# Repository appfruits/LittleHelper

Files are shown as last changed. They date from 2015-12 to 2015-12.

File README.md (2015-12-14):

# LittleHelper
This is the Arduino compatible firmware running Little Helper, a little device that is useful in electronic labs. The firmware also shows how to build a more complex LCD based application, featuring a few standard controls.

This software should compile and run on a Teensy 3.1 although you will need a few hardware components to make use of it. Have a look at http://www.appfruits.com/littlehelper. We provide everything from PCB schematics and layout, even enclosings to build your own Little Helper or getting inspired building your own little, useful device.

Copyright 2014-2015 by Phillip Schuster
http://www.appfruits.com

## Hardware
We also added the Eagle PCBs Design, layout and schematics. We also added the Copper file. Copper is a Mac applications that makes it easy to generate 3D models of your Eagle based PCBs and also helps in building a BOM and keeping it up to date. Have a look at http://www.copper-app.com.

## Structure
This software is C++ and shows how to build a nice, stack based application runloop and User Interface that is easily expandable by providing standard controls and protocols and uses the good old MVC structure. 

Running such code on a small 8-bit AVR is overkill, but with all those new ARM MCUs offering a lot of performance, and more importantly offering more RAM allows such code to be written and run even on small devices. This makes it easier to write structured software that you can read in a couple of months from now.

## License
We provide this in a MIT-License. You may use, copy, modify, merge, publish, distribute, sublicense, and/or sell copies of the Software but you must include this copyright notice and this permission in all copies or substantial portions of the Software.

We invest time and resources making this open source. Please support us by spreading your word and purchasing our products.

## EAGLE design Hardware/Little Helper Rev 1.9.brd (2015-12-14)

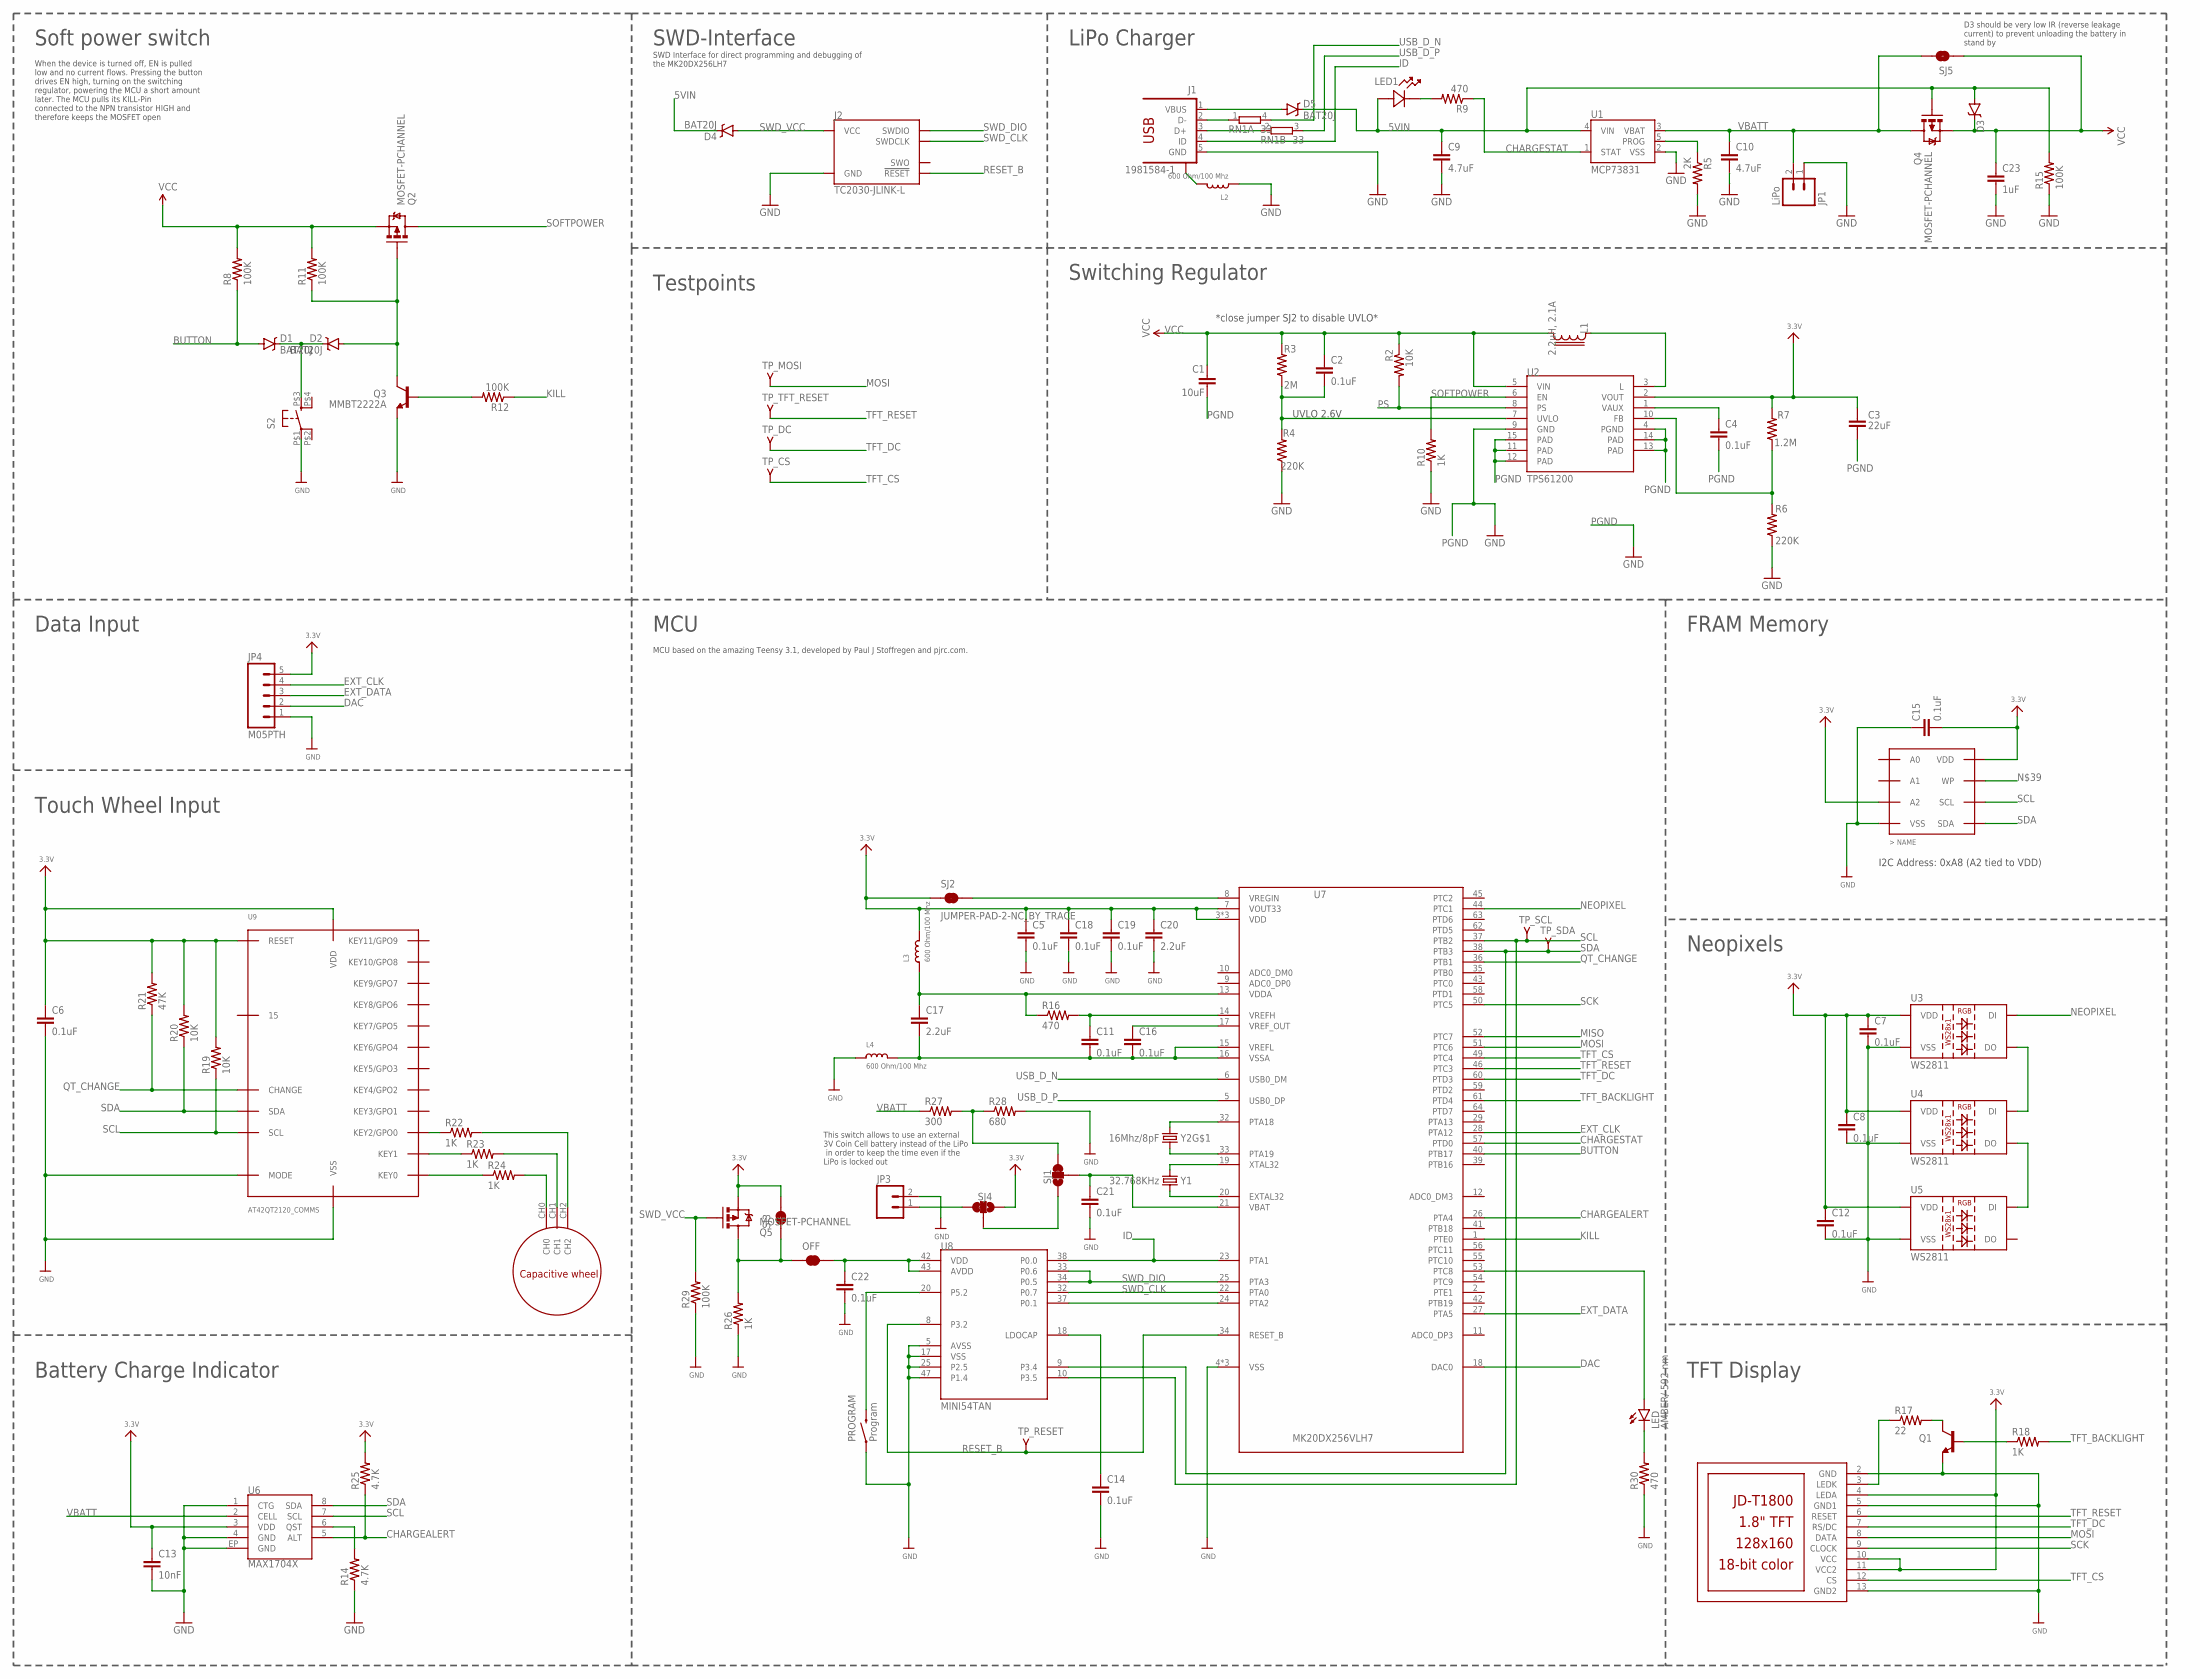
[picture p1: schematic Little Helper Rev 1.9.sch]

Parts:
C1: 10uF; 0603-CAP
C2, C4, C5, C6, C7, C8, C11, C12, C14, C15, C16, C18, C19, C21, C22: 0.1uF; 0603-CAP
C3: 22uF; 0603-CAP
C9, C10: 4.7uF; 0603-CAP
C13: 10nF; 0603-CAP; MPN C0603C103K5RACTU
C17, C20: 2.2uF; 0603-CAP
C23: 1uF; 0603-CAP
D1, D2, D4, D5: BAT20J; SOD-323
D3: DIODE-SCHOTTKY-LOW_LEAKAGE; SOD-323
J1: 1981584-1; MPN ZX62-AB-5PA(11)
J2: TC2030-JLINK-L; TC2030-IDC
JP1: LiPo; JST-2-SMD
JP3: M02PTH; 1X02
JP4: M05PTH; 1X05
L1: 2.2uH, 2.1A; LPS3015
L2, L3, L4: 600 Ohm/100 Mhz; 0805
LCD1: JD-T1800
LED: AMBER/ 592 nm; LED-0603
LED1: 597-2311-407F; LED_597-2311-407F
OFF: JUMPER-PAD-2-NC_BY_TRACE; PAD-JUMPER-2-NC_BY_TRACE_YES_SILK
PROGRAM: Program; TACTILE-SWITCH-1101NE; MPN RS-282G05A3-SM RT
Q1: TRANSISTOR_NPNSOT23-3; SOT23-3
Q2, Q4, Q5: MOSFET-PCHANNEL; SOT23-3; MPN BSS84LT1G
Q3: MMBT2222A; SOT23-3
R2, R19, R20: 10K; 0603-RES
R3: 2M; 0603-RES
R4, R6: 220K; 0603-RES
R5: 2K; 0603-RES
R7: 1.2M; 0603-RES
R8, R11, R12, R15, R29: 100K; 0603-RES
R9, R16, R30: 470; 0603-RES
R10, R18, R22, R23, R24, R26: 1K; 0603-RES
R14, R25: 4.7K; 0603-RES
R17: 22; 0603-RES
R21: 47K; 0603-RES
R27: 300; 0603-RES
R28: 680; 0603-RES
RN1: 33; EXB34V; MPN EXB-34V330JV
S2: TAC_SWITCHPTS645_SERIES; PTS645_BUTTON_SERIES; MPN PTS645SH50SMTR 92 LFS
SJ1, SJ4: JUMPER-PAD-3-2OF3_NC_BY_TRACE; PAD-JUMPER-3-2OF3_NC_BY_TRACE_YES_SILK_FULL_BOX
SJ2: JUMPER-PAD-2-NC_BY_TRACE; PAD-JUMPER-2-NC_BY_TRACE_YES_SILK
SJ3, SJ5: JUMPER-PAD-2-NOYES_SILK; PAD-JUMPER-2-NO_YES_SILK
TP_CS: TPV-PAD-016; PAD-016
TP_DC: TPV-PAD-016; PAD-016
TP_MOSI: MOSI; PAD-016
TP_RESET: TPV-PAD-016; PAD-016
TP_SCL: TPV-PAD-016; PAD-016
TP_SDA: TPV-PAD-016; PAD-016
TP_TFT_RESET: MOSI; PAD-016
U1: MCP73831; SOT23-5; MPN MCP73831T-2ACI/OT
U2: TPS61200; QFN-10_PAD
U3, U4, U5: WS2811; LED-TRICOLOR-5050-IC
U6: MAX1704X; TDFN-8
U7: MK20DX256VLH7; MPN MK20DX256VLH7
U8: MINI54TAN
U9: AT42QT2120_COMMS; QT2120
U12: FM24CL64BSOIC8_150MIL; SO08
U$1: QTWHEEL_MODULE; QTWHEELMODULE
Y1: 32.768KHz; CRYSTAL-TXC-7A; MPN FC-255 32.7680K-A3
Y2: 16Mhz/8pF; CRYSTAL-SMD-5X3; MPN ECS-160-8-30B-CKM

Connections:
3.3V: C3.1, C5.1, C6.1, C7.1, C8.1, C12.1, C13.1, C15.2, C18.1, C19.1, C20.1, JP4.5, L3.2, LCD1.4 (LEDA), LCD1.10 (VCC), LCD1.11 (VCC2), Q5.2 (S), R7.2, R19.2, R20.2, R21.2, R25.2, SJ2.1, SJ3.2, SJ4.1, U2.2 (VOUT), U3.3 (VDD), U3.5 (VDD), U4.3 (VDD), U4.5 (VDD), U5.3 (VDD), U5.5 (VDD), U6.3 (VDD), U7.3 (VDD), U7.7 (VOUT33), U7.30 (VDD), U7.48 (VDD), U9.11 (VDD), U9.14 (RESET), U12.3 (A2), U12.8 (VDD)
5VIN: C9.1, D3.A, D4.C, D5.C, LED1.2, Q4.1 (G), R15.2, U1.4 (VIN)
BUTTON: D1.A, R8.1, U7.40 (PTB17)
CHARGEALERT: R25.1, U6.5 (ALT), U7.26 (PTA4)
CHARGESTAT: R9.1, U1.1 (STAT), U7.57 (PTD0)
DAC: JP4.2, U7.18 (DAC0)
EXT_CLK: JP4.4, U7.28 (PTA12)
EXT_DATA: JP4.3, U7.27 (PTA5)
FB: R6.2, R7.1, U2.10 (FB)
GND: C5.2, C6.2, C7.2, C8.2, C9.2, C10.2, C12.2, C13.2, C14.2, C15.1, C18.2, C19.2, C20.2, C21.2, C22.2, C23.2, J1.5 (GND), J2.5 (GND), JP1.1 (2), JP3.2, JP4.1, L2.1, L4.1, LCD1.2 (GND), LCD1.5 (GND1), LCD1.13 (GND2), PROGRAM.P$1 (1), Q1.2 (E), Q3.2 (E), R4.1, R5.2, R6.1, R10.1, R14.1, R15.1, R26.1, R28.2, R29.1, R30.1, S2.P$1 (1), U1.2 (VSS), U3.6 (VSS), U4.6 (VSS), U5.6 (VSS), U6.1 (CTG), U6.4 (GND), U6.EP (GND), U7.4 (VSS), U7.31 (VSS), U7.47 (VSS), U8.5 (AVSS), U8.17 (VSS), U8.25 (P2.5), U8.47 (P1.4), U9.10 (VSS), U9.12 (MODE), U12.4 (VSS)
ID: J1.4 (ID), U7.23 (PTA1), U8.38 (P0.0)
KILL: R12.1, U7.1 (PTE0)
MISO: U7.52 (PTC7)
MOSI: LCD1.8 (DATA), TP_MOSI.1, U7.51 (PTC6)
unnamed: OFF.1, Q5.3 (D), R26.2, SJ3.1
unnamed: L1.1, U2.3 (L)
unnamed: D2.A, Q2.1 (G), Q3.3 (C), R11.1
unnamed: Q3.1 (B), R12.2
unnamed: D1.C, D2.C, S2.P$3 (3)
unnamed: LED1.1, R9.2
unnamed: C21.1, SJ1.2, U7.21 (VBAT)
unnamed: C22.1, OFF.2, U8.42 (VDD), U8.43 (AVDD)
unnamed: R5.1, U1.5 (PROG)
unnamed: LED.A, U7.53 (PTC8)
unnamed: D5.A, J1.1 (VBUS)
unnamed: JP3.1, SJ4.3
unnamed: U7.24 (PTA2), U8.37 (P0.1)
unnamed: R22.1, U9.7 (KEY2/GPO0)
unnamed: R23.1, U9.8 (KEY1)
unnamed: LED.C, R30.2
unnamed: PROGRAM.P$2 (2), U8.20 (P5.2)
unnamed: SJ1.1, SJ4.2
unnamed: C14.1, U8.18 (LDOCAP)
unnamed: U7.32 (PTA18), Y2.3 (2)
unnamed: U7.33 (PTA19), Y2.1
unnamed: U7.19 (XTAL32), Y1.P$2 (2)
unnamed: U7.20 (EXTAL32), Y1.P$1 (1)
unnamed: R27.2, R28.1, SJ1.3
unnamed: LCD1.3 (LEDK), R17.1
unnamed: R24.1, U9.9 (KEY0)
unnamed: U3.1 (DO), U4.2 (DI)
unnamed: Q1.3 (C), R17.2
unnamed: Q1.1 (B), R18.1
unnamed: R22.2, U$1.CH2
unnamed: R23.2, U$1.CH1
unnamed: R24.2, U$1.CH0
unnamed: U4.1 (DO), U5.2 (DI)
unnamed: R14.2, U6.6 (QST)
NEOPIXEL: U3.2 (DI), U7.44 (PTC1)
PGND: C1.2, C3.2, C4.2, U2.4 (PGND), U2.9 (GND), U2.11 (PAD), U2.12 (PAD), U2.13 (PAD), U2.14 (PAD), U2.15 (PAD)
PS: R2.2, U2.8 (PS)
QT_CHANGE: R21.1, U7.36 (PTB1), U9.17 (CHANGE)
RESET_B: J2.3 (!RESET), TP_RESET.1, U7.34 (RESET_B), U8.8 (P3.2)
SCK: LCD1.9 (CLOCK), U7.50 (PTC5)
SCL: R19.1, TP_SCL.1, U6.7 (SCL), U7.37 (PTB2), U8.10 (P3.5), U9.16 (SCL), U12.6 (SCL)
SDA: R20.1, TP_SDA.1, U6.8 (SDA), U7.38 (PTB3), U8.9 (P3.4), U9.13 (SDA), U12.5 (SDA)
SOFTPOWER: Q2.3 (D), R10.2, U2.6 (EN)
SWD_CLK: J2.4 (SWDCLK), U7.22 (PTA0), U8.32 (P0.7)
SWD_DIO: J2.2 (SWDIO), U7.25 (PTA3), U8.33 (P0.6), U8.34 (P0.5)
SWD_VCC: D4.A, J2.1 (VCC), Q5.1 (G), R29.2
TFT_BACKLIGHT: R18.2, U7.61 (PTD4)
TFT_CS: LCD1.12 (CS), TP_CS.1, U7.49 (PTC4)
TFT_DC: LCD1.7 (RS/DC), TP_DC.1, U7.60 (PTD3)
TFT_RESET: LCD1.6 (RESET), TP_TFT_RESET.1, U7.46 (PTC3)
USB_CON_N: J1.2 (D-), RN1.1
USB_CON_P: J1.3 (D+), RN1.2 (1)
USB_D_N: RN1.4 (2), U7.6 (USB0_DM)
USB_D_P: RN1.3 (2), U7.5 (USB0_DP)
USB_SHIELD: J1.S1, L2.2
UVLO: C2.2, R3.1, R4.2, U2.7 (UVLO)
VAUX: C4.1, U2.1 (VAUX)
VBATT: C10.1, JP1.2 (1), Q4.3 (D), R27.1, SJ5.2, U1.3 (VBAT), U6.2 (CELL)
VCC: C1.1, C2.1, C23.1, D3.C, L1.2, Q2.2 (S), Q4.2 (S), R2.1, R3.2, R8.2, R11.2, SJ5.1, U2.5 (VIN)
VDDA: C17.1, L3.1, R16.1, U7.13 (VDDA)
VREFH: C11.1, R16.2, U7.14 (VREFH)
VREFL: C11.2, C16.2, C17.2, L4.2, U7.15 (VREFL), U7.16 (VSSA)
VREF_OUT: C16.1, U7.17 (VREF_OUT)
VREGIN: SJ2.2, U7.8 (VREGIN)

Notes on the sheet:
UVLO 2.6V
*close jumper SJ2 to disable UVLO*
LiPo Charger
Switching Regulator
Data Input
This switch allows to use an external 3V Coin Cell battery instead of the LiPo in order to keep the time even if the LiPo is locked out
When the device is turned off, EN is pulled low and no current flows. Pressing the button drives EN high, turning on the switching regulator, powering the MCU a short amount later. The MCU pulls its KILL-Pin connected to the NPN transistor HIGH and therefore keeps the MOSFET open
I2C Address: 0xA8 (A2 tied to VDD)
Soft power switch
Battery Charge Indicator
Touch Wheel Input
MCU
FRAM Memory
Neopixels
TFT Display
MCU based on the amazing Teensy 3.1, developed by Paul J Stoffregen and pjrc.com.
SWD Interface for direct programming and debugging of the MK20DX256LH7
SWD-Interface
Testpoints
D3 should be very low IR (reverse leakage current) to prevent unloading the battery in stand by

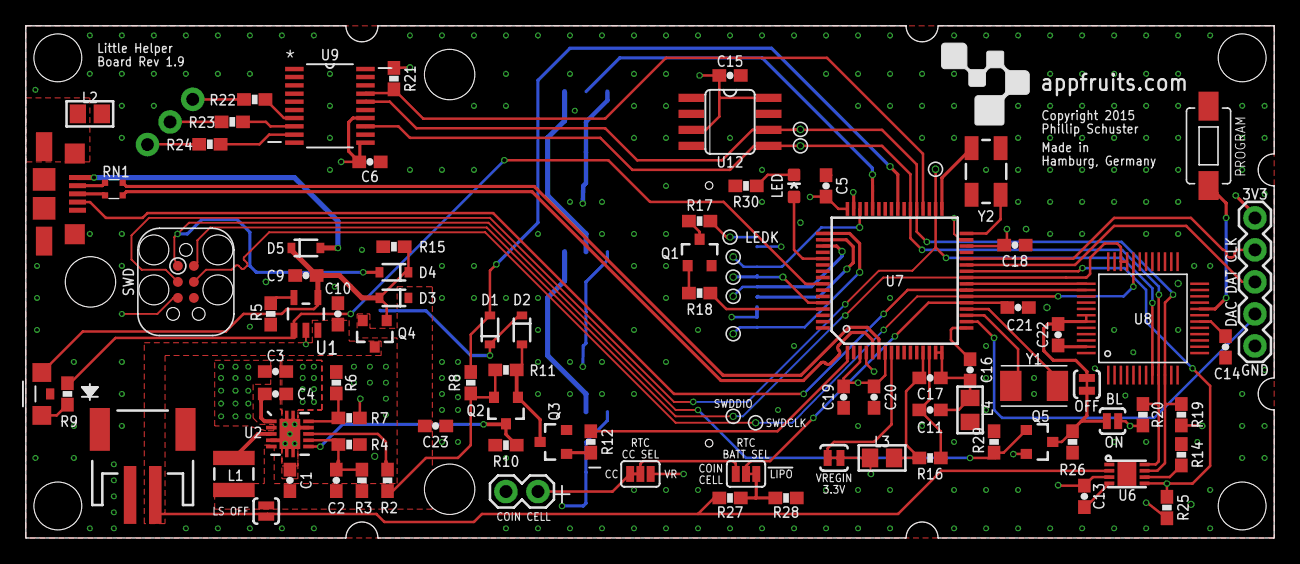
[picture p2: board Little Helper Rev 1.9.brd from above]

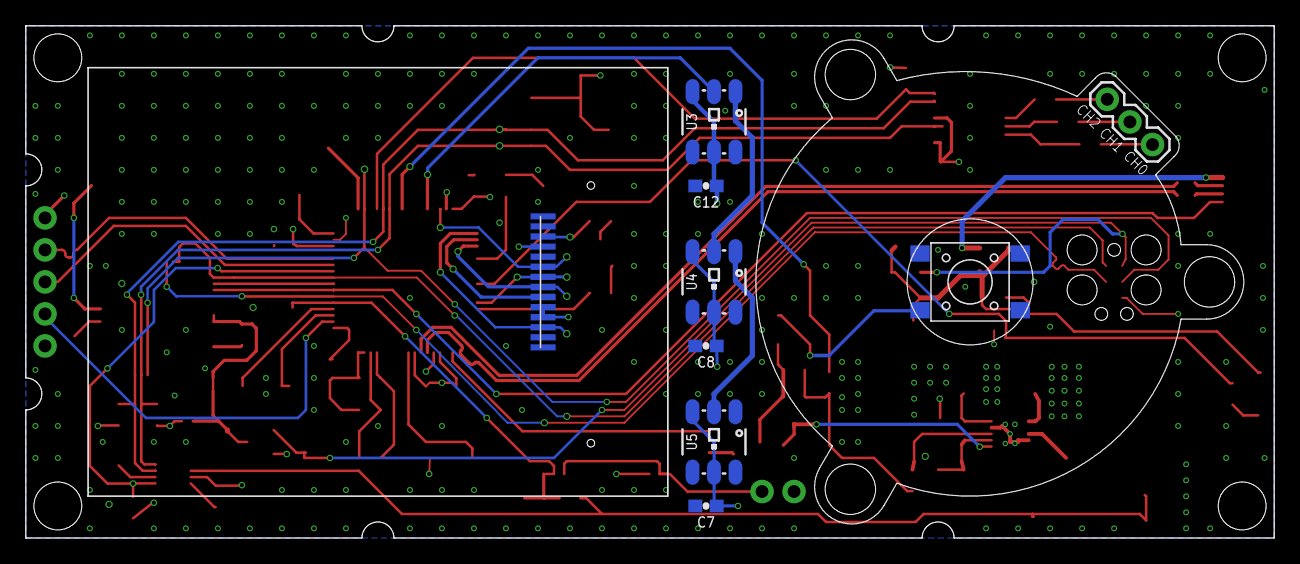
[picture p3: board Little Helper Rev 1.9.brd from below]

Board: 4 copper layers, 99.1 x 40.6 mm, 102 parts (9 on the bottom side), 77 nets.

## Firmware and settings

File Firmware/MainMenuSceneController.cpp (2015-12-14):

/*
 * Little Helper -- your best friend in your lab
 * http://www.appfruits.com/littlehelper
 *
 * This software is part of the firmware running Little Helper. You may use, copy, 
 * modify, merge, publish, distribute, sublicense, and/or sell copies of the Software 
 * but you must include this copyright notice and this permission in all copies or 
 * substantial portions of the Software.
 *
 * Appfruits invests time and resources to make this open source. Please support us
 * and the open-source hardware initiative.
 * 
 * Copyright 2014-2015 Phillip Schuster (@appfruits)
 * http://www.appfruits.com
 * 
 * MIT-License
 */

#include "MainMenuSceneController.h"
#include "MenuItemButtonView.h"
#include "MenuItemWheelView.h"

MainMenuSceneController::MainMenuSceneController() :
		SceneController(),
		_currentMenuView(NULL),
		_mainMenuView("Home",MINX,MINY,MAXW,MAXY-35),
		_settingsMenuView("Settings",MAXX,MINY,MAXW,MAXY-35),
		_menuBackgroundView(MINX,MINY,MAXW,MAXY-35)
{
	_mainMenuView.addMenuItem(new MenuItemButtonView("Settings", this, new MenuAction(&_settingsMenuView, true)));
	_mainMenuView.addMenuItem(new MenuItemButtonView("Analog Out", this));
	_mainMenuView.addMenuItem(new MenuItemButtonView("Clock Out", this));
	_mainMenuView.addMenuItem(new MenuItemButtonView("I2C-Scanner", this));
	_mainMenuView.addMenuItem(new MenuItemButtonView("Scope", this));
	_mainMenuView.addMenuItem(new MenuItemButtonView("LightBox", this));
	_mainMenuView.setVisible(true);

	//Touch-Wheel
	MenuItemWheelView* twThreshold = new MenuItemWheelView("Threshold",this);
	twThreshold->setLimits(0,127);
	twThreshold->setValue(qtouch.getDetectThreshold(0));
	MenuItemWheelView* twIntegrator = new MenuItemWheelView("Integrator",this);
	twIntegrator->setLimits(0,127);
	twIntegrator->setValue(qtouch.getDetectionIntegrator());

	_settingsMenuView.addMenuItem(new MenuItemButtonView("<- Back to Home", this, new MenuAction(&_mainMenuView, false)));
	_settingsMenuView.addMenuItem(new MenuItemButtonView("Brightness", this));
	_settingsMenuView.addMenuItem(new MenuItemButtonView("Speed", this));
	_settingsMenuView.addMenuItem(twThreshold);
	_settingsMenuView.addMenuItem(twIntegrator);
	_settingsMenuView.setVisible(true);

	//Create a background view that fixes animation bugs as we move the whole menu without erasing the background beneath it
	_menuBackgroundView.setBackgroundColor(ST7735_BLACK);
	_menuBackgroundView.setOpaque(true);

	_selectedItem = 0.0f;

	setCurrentMenuView(&_mainMenuView, true);
}


void MainMenuSceneController::onWillAppear()
{
	SceneController::onWillAppear();

	_currentMenuView->setFocus();
}

void MainMenuSceneController::setCurrentMenuView(MenuView *menuView, bool forward)
{
	if (_currentMenuView == menuView) return;

	//Move old view to left
	if (_currentMenuView != NULL)
	{
		if (forward) _currentMenuView->popLeft(true); else _currentMenuView->popRight(true);
	}

	//Activate new view, push to left and set status bar caption
	_currentMenuView = menuView;
	Application.getStatusBar()->setCaption(menuView->getName());
	_currentMenuView->setSelectedItemIndex(0);
	_selectedItem = 0.0f;
	_currentMenuView->setVisible(true);
	_currentMenuView->setFocus();
	if (forward) _currentMenuView->pushLeft(true); else _currentMenuView->pushRight(true);
}

MenuView* MainMenuSceneController::getCurrentMenuView()
{
	return _currentMenuView;
}

void MainMenuSceneController::loop()
{
	_menuBackgroundView.update();
	_mainMenuView.update();
	_settingsMenuView.update();
}

void MainMenuSceneController::menuItemViewTriggered(MenuItemView *menuItemView)
{
	MenuAction* menuAction = (MenuAction*)menuItemView->getObject();
	if (menuAction != NULL)
	{
		MenuView* nextMenuView = menuAction->getNextMenu();
		bool forward = menuAction->isForward();

		if (nextMenuView != NULL)
		{
			setCurrentMenuView(nextMenuView, forward);
			return;
		}
	}
	else if (menuItemView->getTitle() == "Analog Out")
	{
		_analogOutputSceneController = new AnalogOutSceneController();
		Application.pushScene(_analogOutputSceneController);
	}
	else if (menuItemView->getTitle() == "Clock Out")
	{
		_clockOutSceneController = new ClockOutSceneController();
		Application.pushScene(_clockOutSceneController);
	}
	else if (menuItemView->getTitle() == "I2C-Scanner")
	{
		_i2cScannerSceneController = new I2CScannerSceneController();
		Application.pushScene(_i2cScannerSceneController);
	}
	else if (menuItemView->getTitle() == "Scope")
	{
		_scopeSceneController = new ScopeSceneController();
		Application.pushScene(_scopeSceneController);
	}
	else if (menuItemView->getTitle() == "LightBox")
	{
		_lightboxSceneController = new LightBoxSceneController();
		Application.pushScene(_lightboxSceneController);
	}
}


void MainMenuSceneController::menuItemViewValueChanged(MenuItemView *menuItemView, float value)
{
	if (menuItemView->getTitle() == "Threshold")
	{
		for (int i=0;i<3;i++)
		{
			qtouch.setDetectThreshold(i,(int)value);
		}
		LOG_VALUE("Touch-Wheel detection threshold",(int)value);
	}
	else if (menuItemView->getTitle() == "Integrator")
	{
		qtouch.setDetectionIntegrator((int)value);
		LOG_VALUE("Touch-Wheel integrator",(int)value);
	}
}

String MainMenuSceneController::getName()
{
	return "Main-Menu";
}

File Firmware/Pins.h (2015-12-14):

/*
 * Little Helper -- your best friend in your lab
 * http://www.appfruits.com/littlehelper
 *
 * This software is part of the firmware running Little Helper. You may use, copy, 
 * modify, merge, publish, distribute, sublicense, and/or sell copies of the Software 
 * but you must include this copyright notice and this permission in all copies or 
 * substantial portions of the Software.
 *
 * Appfruits invests time and resources to make this open source. Please support us
 * and the open-source hardware initiative.
 * 
 * Copyright 2014-2015 Phillip Schuster (@appfruits)
 * http://www.appfruits.com
 * 
 * MIT-License
 */

#ifndef TEENSYCMAKE_PINS_H
#define TEENSYCMAKE_PINS_H

#include <stdint-gcc.h>
#include "Arduino.h"

#define EXT_PIN_3 3
#define EXT_PIN_2 24
#define EXT_PIN_1 A14
#define EXT_PIN_DAC A14

#define PIN_3V3 4
#define PIN_DAC 3
#define PIN_GND 0

class Pin
{
public:
	Pin(String name, uint16_t color, uint8_t hardwareId) {
		this->_name = name;
		this->_color = color;
		this->_hardwareId = hardwareId;
		this->_active = false;
	}

	bool isActive();
	void setActive(bool active);
	void setName(String name);
	String getName();
	uint8_t getHardwareId();
	uint16_t getColor();

	void setPinMode(uint8_t thePinMode);
	int analogRead();

private:
	String _name;
	uint16_t _color;
	uint8_t _hardwareId;
	bool _active;
};


class PinsClass
{
public:
	PinsClass();

	Pin* getPin(int8_t pos);
	void setPinName(int8_t pos, String name);
	void activatePin(int8_t pos, String name);
	void setPinActive(int8_t pos, bool active);
	bool isPinActive(int8_t pos);
	uint8_t getPinId(int8_t pos);
	void resetPins();

private:
	Pin _pins[5];
};

extern PinsClass Pins;


#endif //TEENSYCMAKE_PINS_H

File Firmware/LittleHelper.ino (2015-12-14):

/*
 * Little Helper -- your best friend in your lab
 * http://www.appfruits.com/littlehelper
 *
 * This software is part of the firmware running Little Helper. You may use, copy, 
 * modify, merge, publish, distribute, sublicense, and/or sell copies of the Software 
 * but you must include this copyright notice and this permission in all copies or 
 * substantial portions of the Software.
 *
 * Appfruits invests time and resources to make this open source. Please support us
 * and the open-source hardware initiative.
 * 
 * Copyright 2014-2015 Phillip Schuster (@appfruits)
 * http://www.appfruits.com
 * 
 * MIT-License
 */

#include "Application.h"
#include "MainMenuSceneController.h"

Appfruits_ST7735 display = Appfruits_ST7735(cs, dc, rst);
Appfruits_QTouch qtouch = Appfruits_QTouch(14);
TouchWheel touchWheel(&qtouch);
Adafruit_NeoPixel leds = Adafruit_NeoPixel(numPixels, neoPixelPin, NEO_GRB + NEO_KHZ800);
Appfruits_Button button = Appfruits_Button(buttonPin);
MAX1704 battery = MAX1704();

MainMenuSceneController* mainMenu;

void selfCheck()
{
	byte error, address;
	int nDevices;

	Serial.println("Scanning...");

	nDevices = 0;
	for(address = 1; address < 127; address++ )
	{
		// The i2c_scanner uses the return value of
		// the Write.endTransmisstion to see if
		// a device did acknowledge to the address.
		Wire.beginTransmission(address);
		error = Wire.endTransmission();

		if (error == 0)
		{
			Serial.print("I2C device found at address 0x");
			if (address<16)
				Serial.print("0");
			Serial.print(address,HEX);
			Serial.println("  !");

			nDevices++;
		}
		else if (error==4)
		{
			Serial.print("Unknow error at address 0x");
			if (address<16)
				Serial.print("0");
			Serial.println(address,HEX);
		}
	}
	if (nDevices == 0)
		Serial.println("No I2C devices found\n");
	else
		Serial.println("done\n");
}

void setup()
{
	//Neopixels
	LOG("Initializing pixels");
	leds.begin();
	leds.setBrightness(40);
	leds.setPixelColor(0,0);
	leds.setPixelColor(1,255,255,255);
	leds.setPixelColor(2,0);
	leds.show();

	//Initialize Serial
	Serial.begin(230400);

	//Initialize I2C
	Wire.begin();

	//Display on
	LOG("Activating LCD-Backlight");
	pinMode(lcdBacklightPin,OUTPUT);
	digitalWrite(lcdBacklightPin,HIGH);

	//Turn device on
	LOG("Setting Kill pin");
	pinMode(killPin,OUTPUT);
	digitalWrite(killPin,HIGH);

	leds.setPixelColor(1,0);
	leds.show();

	//LED
	LOG("Configuring built in LED");
	pinMode(ledPin,OUTPUT);

	//Init display
	LOG("Initializing display");
	display.initR(INITR_BLACKTAB);
	display.setRotation(2);
	display.clear(ST7735_BLACK);

	//Setup chargealert
	//pinMode(chargeAlertPin,INPUT_PULLUP);

	//Setup button
	LOG("Initializing Wheel-Button");
	button.begin();

	//Init touch
	LOG("Initializing touch wheel");
	touchWheel.begin();

	LOG("Starting MainMenu");
	mainMenu = new MainMenuSceneController();
	Application.pushScene(mainMenu);
}

void loop()
{
	Application.loop();
}

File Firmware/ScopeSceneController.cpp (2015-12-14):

/*
 * Little Helper -- your best friend in your lab
 * http://www.appfruits.com/littlehelper
 *
 * This software is part of the firmware running Little Helper. You may use, copy, 
 * modify, merge, publish, distribute, sublicense, and/or sell copies of the Software 
 * but you must include this copyright notice and this permission in all copies or 
 * substantial portions of the Software.
 *
 * Appfruits invests time and resources to make this open source. Please support us
 * and the open-source hardware initiative.
 * 
 * Copyright 2014-2015 Phillip Schuster (@appfruits)
 * http://www.appfruits.com
 * 
 * MIT-License
 */

#include "ScopeSceneController.h"

static ScopeSceneController* _currentScopeSceneController = NULL;
static bool inInterrupt = false;

void onScopeTimerTick(void)
{
	if (_currentScopeSceneController != NULL)
	{
		int sample = Pins.getPin(1)->analogRead();
		_currentScopeSceneController->addSample(sample);
	}
}

ScopeSceneController::ScopeSceneController():
	_scopeView(this,MINX,MINY,MAXW,MAXH-20),
	_menuView("Controls",MINX,MINY+MAXH-20,MAXW,20,false),
	_numSamples(0),
	_paused(false),
	_labelView("Hallo",MINX,MINY+40,MAXW,15)
{
	_scopeView.setDelegate(this);
	_scopeView._currentRecord = &_record;
	_numTriggers = 0;
	_triggerSlot = 0;
	_triggered = false;
	_previousSample = 0;
	_triggerSlope = Slope::Raising;

	_xScaleItemView = new MenuItemWheelView("xS",this);
	//_xScaleItemView->setTitle("<*>");
	_xScaleItemView->setLimits(0.1f,10.0f);

	_xPosItemView = new MenuItemWheelView("xP",this);
	//_xPosItemView->setTitle("<+>");
	_xPosItemView->setLimits(-64,64);

	_triggerItemView = new MenuItemEnumView("T",this);
	_triggerItemView->addItem(0,"Raise");
	_triggerItemView->addItem(1,"Fall");
	_triggerItemView->addItem(2,"Both");
	_triggerItemView->addItem(3,"Off");

	_menuView.addMenuItem(_xScaleItemView);
	_menuView.addMenuItem(_xPosItemView);
	_menuView.addMenuItem(_triggerItemView);
}


String ScopeSceneController::getName()
{
	return "ScopeSceneController";
}

bool ScopeSceneController::isPaused()
{
	return _paused;
}

void ScopeSceneController::onWillAppear()
{
	SceneController::onWillAppear();

	Pins.activatePin(1,"Channel 1");
	//Pins.activatePin(2,"Channel 2");
	Pins.activatePin(PIN_GND,"GND");

	Pins.getPin(1)->setPinMode(INPUT);
	//Pins.getPin(2)->setPinMode(INPUT);

	Application.getStatusBar()->setCaption("Scope");

	_menuView.setFocus();

	_currentScopeSceneController = this;

	_timer.begin(onScopeTimerTick,500);
}

void ScopeSceneController::onWillDisappear()
{
	SceneController::onWillDisappear();

	_timer.end();
	_currentScopeSceneController = NULL;
}

/*
 *
 * 	display.println(length+start);
		this->_delegate->copySamples(numSamples+start,abs(start),&_samples[0]);
		this->_delegate->copySamples(0,length + start,&_samples[abs(start)]);
	}
	else
	{
		if (end < numSamples)
		{
			display.print("S-Start:");
			display.println(start);
			display.print("S-Length:");
			display.println(length);
			display.println(length+start);

			this->_delegate->copySamples(start,length,&_samples[0]);
		}
		else
		{
			display.print("S1-Start:");
			display.println(start);
			display.print("S2-Length:");
			display.println(numSamples-start);
			display.print("S2-Start:");
			display.println(0);
			display.print("S2-Length");
			display.println(end-numSamples);

			this->_delegate->copySamples(start,numSamples-start,&_samples[0]);
			this->_delegate->copySamples(0,end-numSamples,&_samples[numSamples-start]);
		}
	}
 */

void ScopeSceneController::copySamples(int start, int end, Record *record)
{
	int s = start;
	int l = end - start;
	if (start < 0)
	{
		s = MAX_SAMPLES + start;
		l = abs(start);

		memcpy(&record->samples[0],&_samples[s],sizeof(int)*l);
		memcpy(&record->samples[l],&_samples[0],sizeof(int)*end);
	}
	else
	{
		if (end < MAX_SAMPLES)
		{
			memcpy(&record->samples[0],&_samples[s],sizeof(int)*l);
		}
		else
		{
			l = MAX_SAMPLES - start;
			memcpy(&record->samples[0],&_samples[start],sizeof(int)*l);
			memcpy(&record->samples[l],&_samples[0],sizeof(int)*(end-MAX_SAMPLES));
		}
	}
}

void ScopeSceneController::addSample(int value)
{
	if (inInterrupt) return;
	inInterrupt = true;
	if (_paused) return;

	_samples[_numSamples] = value;

	if (_triggered == false)
	{
		//Check triggers
		bool triggered = false;
		if (_triggerSlope == Slope::Falling && (_previousSample-value > 500))
		{
			triggered = true;
		}
		if (_triggerSlope == Slope::Raising && (value - _previousSample > 500))
		{
			triggered = true;
		}
		if (_triggerSlope == Slope::Both && (abs(_previousSample-value) > 500))
		{
			triggered = true;
		}

		if (triggered)
		{
			{
				_samplesInTrigger = 0;
				_currentTriggerSlot = _numSamples;
				_triggered = true;
				_numTriggers++;
			}
		}
	}
	else
	{
		_samplesInTrigger++;
		if (_samplesInTrigger > 64)
		{
			_triggered = false;
			_triggerSlot = _currentTriggerSlot;
			_triggers[_numTriggers] = _triggerSlot;
		}
	}

	//Advance memory position
	_numSamples++;
	if (_numSamples >= MAX_SAMPLES)
	{
		_numSamples = 0;

/*		_paused = true;

		Serial.println("Samples");
		for (int i=0;i<MAX_SAMPLES;i++)
		{
			Serial.print(i);
			Serial.print(";");
			Serial.println(_samples[i]);
		}
		Serial.println("Triggers");
		for (int i=0;i<_numTriggers;i++)
		{
			Serial.print(i);
			Serial.print(";");
			Serial.println(_triggers[i]);
		}*/
	}

	_samplesPerSecond= 1000000 / (micros() - _lastTick);
	_lastTick = micros();

	//Save value to compare in next sample
	_previousSample = value;

	inInterrupt = false;
}

void ScopeSceneController::loop()
{
	SceneController::loop();

	if (!_paused)
	{
		int lastTriggerSlot;
		int triggerSlot;

		noInterrupts();
		lastTriggerSlot = _lastTriggerSlot;
		triggerSlot = _triggerSlot;
		interrupts();

		if (lastTriggerSlot != triggerSlot)
		{
			_record.reset();
			_record.startPos = triggerSlot - 64;
			_record.endPos = triggerSlot + 64;

			copySamples(_record.startPos,_record.endPos,&_record);
			_scopeView.setNeedsDisplay();

			noInterrupts();
			this->_lastTriggerSlot = this->_triggerSlot;
			interrupts();
		}
		else if (_triggerSlope == Slope::Off)
		{
			_record.reset();
			noInterrupts();
			int numSamples = _numSamples;
			interrupts();
			_record.startPos = numSamples - 1 - 128;
			_record.endPos = numSamples - 1;

			copySamples(_record.startPos,_record.endPos,&_record);
			_scopeView.setNeedsDisplay();
		}
	}

	if (_paused)
	{
		//_scopeView.update();
	}
	else
	{
/*		int sample = Pins.getPin(1)->analogRead();
		//sample = random(-127,127);

		_samples[_numSamples] = sample;
		_numSamples++;
		if (_numSamples >= MAX_SAMPLES)
		{
			_numSamples = 0;
			_scopeView.setCursor(0);
		}

		_scopeView.setCursor(_scopeView.getCursor()+1);*/

		//_scopeView.setNeedsDisplay();
		//_scopeView.update();
	}

	_scopeView.update();
	_labelView.update();
	_menuView.update();
}
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

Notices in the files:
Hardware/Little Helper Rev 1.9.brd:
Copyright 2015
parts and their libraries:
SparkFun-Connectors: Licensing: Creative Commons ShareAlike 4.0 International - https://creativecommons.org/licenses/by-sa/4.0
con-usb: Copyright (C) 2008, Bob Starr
